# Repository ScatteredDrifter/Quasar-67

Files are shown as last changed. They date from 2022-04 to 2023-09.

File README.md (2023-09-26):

# Quasar-67
A Lumberjack Ortho keyboard for the kbd67-lite l

made by **Bonk** and **ScatteredDrifter**

---

Measurements of the pcb are taken from [Elmos Drop in Replacement[(https://github.com/kb-elmo/67mk_E)

---

### Current Status
- rev1 pcb were ordered and **work** well so far. 
- first designs of possible middle-blocker were made and mounted.
- rev1 pcb successfully built with kbd67-lite
 
---
### Quasar-67: 

A quasar defines the center of a galaxy that emits a bright  light, creating the mirage that it is a large star. However they are actually black holes which _emit_ light, due to th massive amount of matter that sourrounds their event horizon, which they consume constantly. 
Being heavily inspired by the lumberjack [find it here](https://github.com/peej/lumberjack-keyboard) this keyboard aims to fit within the affordable kbd67-lite while getting rid of the present 60% keyboard it is.

To build one yourself, you'll need the pcb - files can be find in production/... - and a plate made of the material you prefer. All production files can be found within this repository. 

### Build Guide: 

**// ought to be added before release 02 //**

### Features: 
- RP2040 
- Usb-C connector 
- short circuit protection to secure the board from electrical discharges and similiar. 
- cutouts for the kbd67-lite 
- two Iso-Enters for thumb cluster >> included in most base-kits 
- options to build this board with 2 encoders on each side 
- option between 5x6 or 5x5 cluster for each side 
- option to mount a Cirque trackpad
- layout options
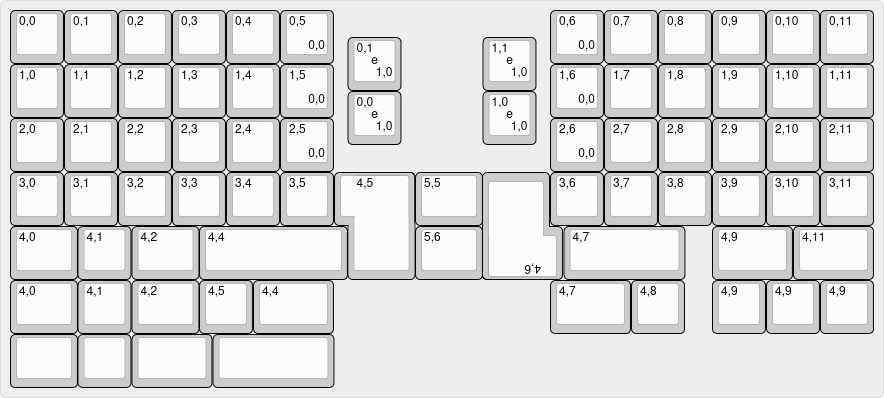
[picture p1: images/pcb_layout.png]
layout of Quasar-67


---
### Images:

**// to be added //**

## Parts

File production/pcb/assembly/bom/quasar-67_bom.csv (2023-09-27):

Comment | Designator | Footprint | LCSC
10u | C1,C4,C17 | Capacitor_SMD:C_0805_2012Metric | C91245
22pf | C2,C3 | Capacitor_SMD:C_0805_2012Metric | C1804
100n | C5,C6,C7,C9,C11,C12,C13,C14 | Capacitor_SMD:C_0805_2012Metric | C49678
1u | C8,C10 | Capacitor_SMD:C_0805_2012Metric | C28323
BAV70 | D1,D2,D3,D55,D56,D203,D407,D506,D809,D1011,D1213,D1415,D1617,D1819,D2021,D2223,D2425,D2627,D2829,D3031,D3233,D3435,D3637,D3839,D4041,D4243,D4445,D4647,D10011,D110111,D210211,D310311,D410411 | Package_TO_SOT_SMD:SOT-23 | C68978
WS2812B | DLED0,DLED1,DLED2,DLED3,DLED4,DLED0.5 | LED_SMD:LED_WS2812B_PLCC4_5.0x5.0mm_P3.2mm
RotaryEncoder_Switch | ENCODERLEFT1,ENCODERRIGHT1,ENCODERLEFT2,ENCODERRIGHT2 | Rotary_Encoder:RotaryEncoder_Alps_EC11E-Switch_Vertical_H20mm
polyfuse | F0 | Fuse:Fuse_1206_3216Metric | C69688
USB_C_Receptacle_USB2.0 | J0 | Connector_USB:USB_C_Receptacle_HRO_TYPE-C-31-M-12 | C165948
BREAKOUT | J1 | Connector_PinSocket_2.54mm:PinSocket_1x05_P2.54mm_Vertical
Conn_01x04_Female | J2 | Connector_PinHeader_2.54mm:PinHeader_1x04_P2.54mm_Vertical
Conn_01x04_Male | J3 | kbd:Aio3_jst | C160404
Conn_01x01_Male | J4 | Connector_PinSocket_1.27mm:PinSocket_1x01_P1.27mm_Vertical
Conn_01x02_Female | J5 | Connector_PinHeader_2.54mm:PinHeader_1x02_P2.54mm_Vertical
Conn_01x04_Male | J6 | Connector_PinSocket_2.54mm:PinSocket_1x04_P2.54mm_Vertical
1k | R1,R5 | Resistor_SMD:R_0805_2012Metric | C115316
27 | R3,R4 | Resistor_SMD:R_0805_2012Metric | C104170
5.1k | R6,R7 | Resistor_SMD:R_0805_2012Metric | C27834
10k | R8 | Resistor_SMD:R_0805_2012Metric | C115309
RESET | SW-1 | Keebio-Parts:SW_SPST_TL3342 | C2886894
RESET | SW-2 | Keebio-Parts:SW_SPST_TL3342 | C2886894
SW_SPST | SW0,SW1,SW2,SW3,SW4,SW5,SW6,SW7,SW8,SW9,SW1.0,SW10,SW1.1,SW11,SW1.2,SW12,SW13,SW14,SW15,SW16,SW17,SW18,SW19,SW20,SW21,SW22,SW23,SW24,SW25,SW26,SW27,SW28,SW29,SW30,SW31,SW32,SW33,SW34,SW35,SW36,SW37,SW38,SW39,SW40,SW41,SW42,SW43,SW44,SW45,SW46,SW47,SW48,SW49,SW50,SW51,SW52,SW53,SW55,SW56,SW57,SW110,SW111,SW210,SW211,SW310,SW311,SW411 | Keebio-Parts:MX-Alps-Choc-1U-NoLED
XC6206PxxxMR | U1 | Package_TO_SOT_SMD:SOT-23 | C347376
W25Q128JVS | U2 | Package_SO:SOIC-8_5.23x5.23mm_P1.27mm | C97521
RP2040 | U3 | RP2040:RP2040-QFN-56 | C2040
SRV05-4 | U44 | Package_TO_SOT_SMD:SOT-23-6 | C85364
12MHZ Crystal | Y0 | Crystal:Crystal_SMD_3225-4Pin_3.2x2.5mm | C9002

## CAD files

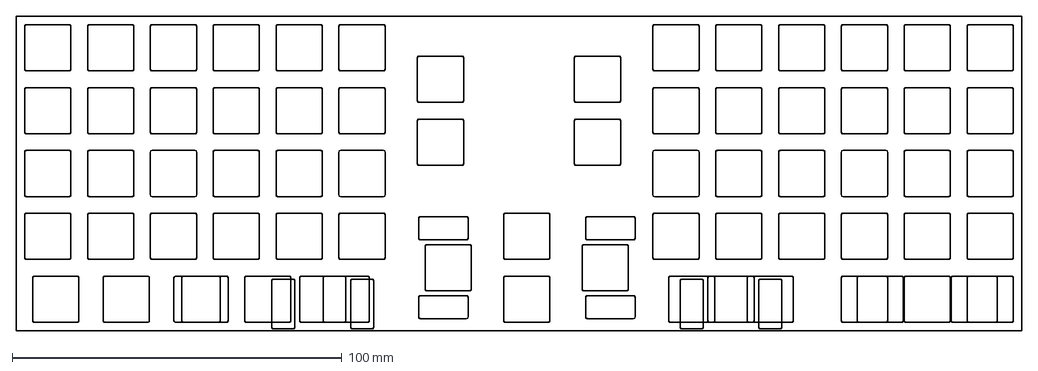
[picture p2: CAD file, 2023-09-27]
newest_plate_pcb_alignment.dxf
304.8 x 95.2 mm

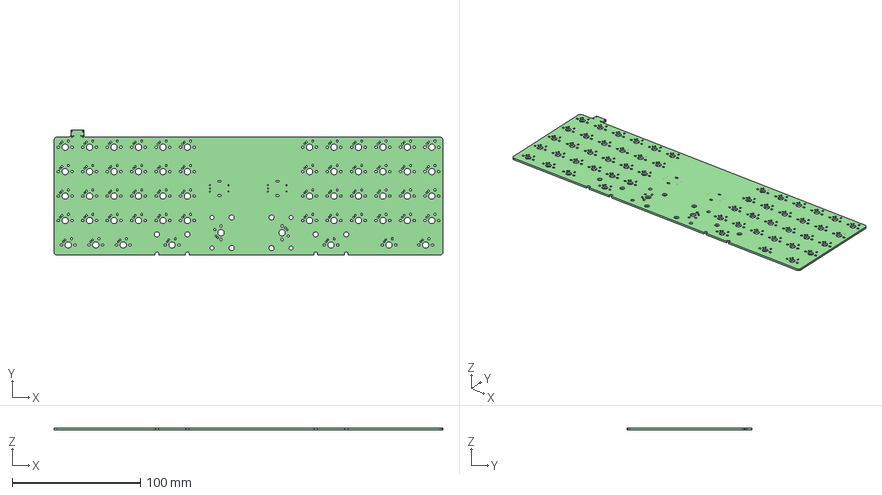
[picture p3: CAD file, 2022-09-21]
pcb/32u4.step
303.2 x 97.6 x 1.60 mm

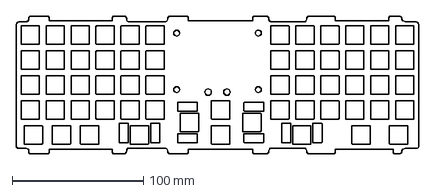
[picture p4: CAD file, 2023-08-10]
plate/Switchplate-maxkeys.dxf
307.2 x 104.9 mm

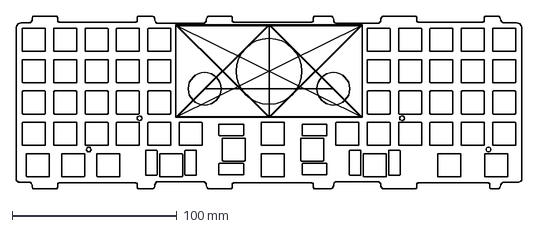
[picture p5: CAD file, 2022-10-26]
newplate_quasar.dxf
307.3 x 104.9 mm

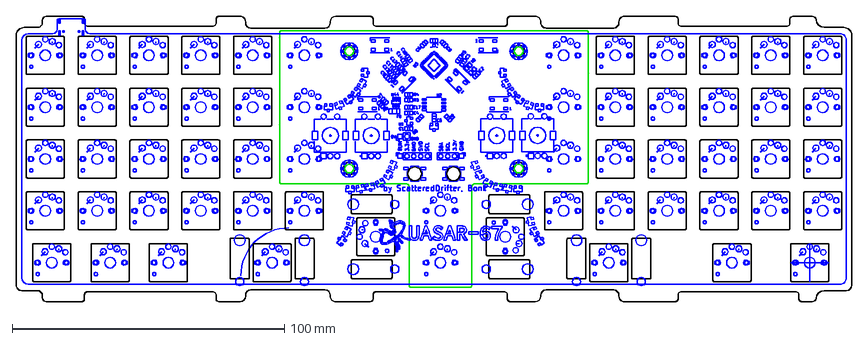
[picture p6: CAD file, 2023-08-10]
plate/All-Plates-4x5-isothumbs-quasarrgb.dxf
307.3 x 104.9 mm

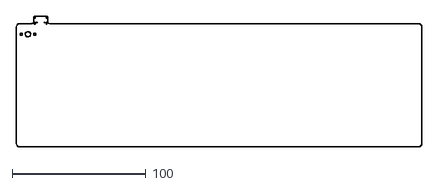
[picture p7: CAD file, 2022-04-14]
elmo_outlines_kbd67.dxf
303.2 x 97.6

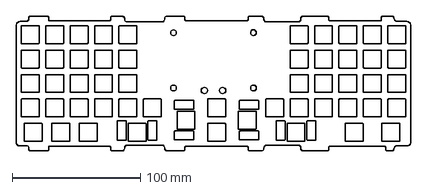
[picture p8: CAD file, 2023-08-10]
plate/Switchplate-botkeys.dxf
307.2 x 104.9 mm

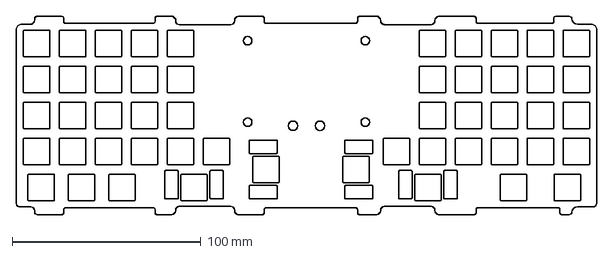
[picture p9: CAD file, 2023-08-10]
plate/Switchplate-4x5-isothumbs.dxf
307.2 x 104.9 mm

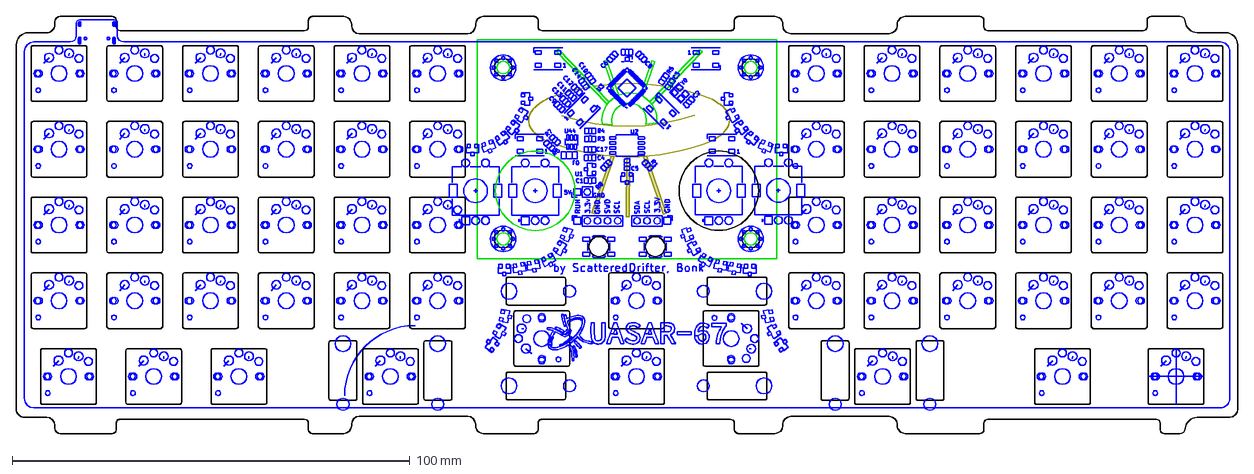
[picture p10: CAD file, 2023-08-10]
plate/All-Plates-maxkeys-encoder.dxf
307.3 x 104.9 mm

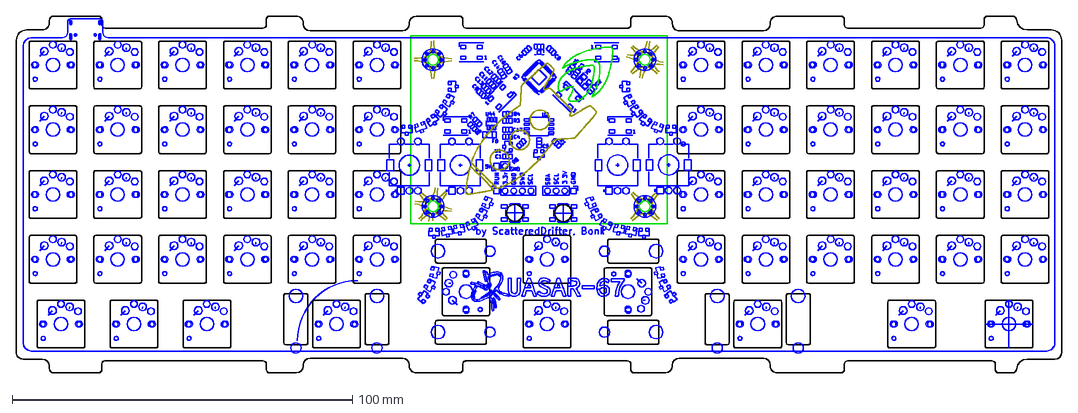
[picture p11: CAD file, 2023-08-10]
plate/All-Plates-maxkeys-rocket.dxf
307.3 x 104.9 mm

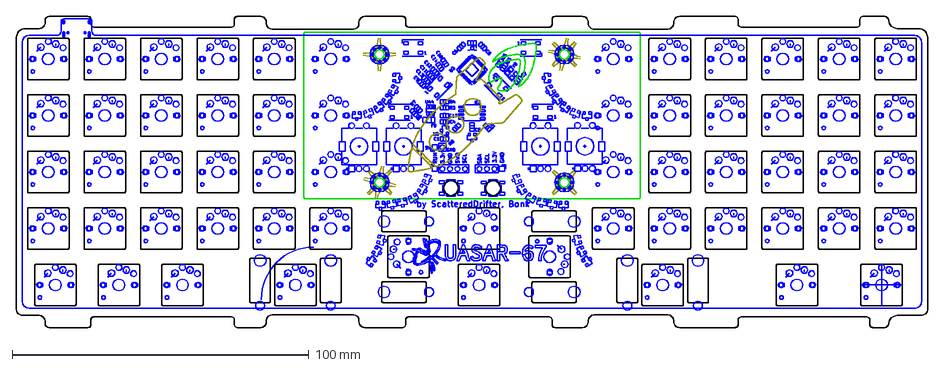
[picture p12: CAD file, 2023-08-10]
plate/All-Plates-botkeys-rocket.dxf
307.3 x 104.9 mm

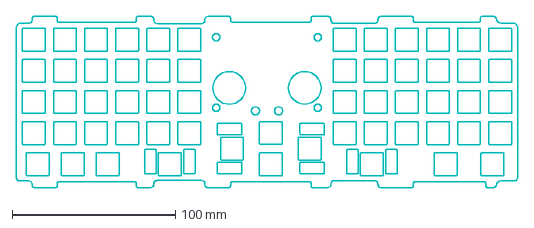
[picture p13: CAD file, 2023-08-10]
plate/Switchplate-maxkeys-encoder.dxf
307.2 x 104.9 mm

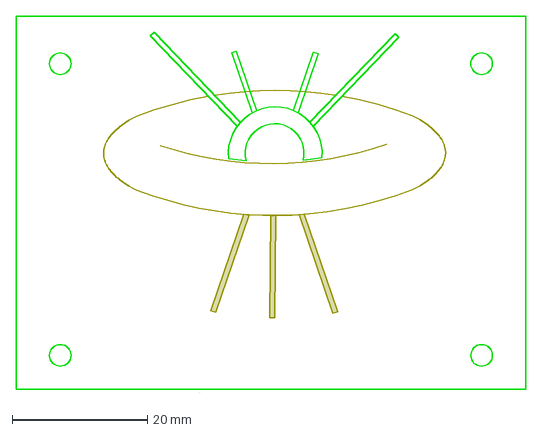
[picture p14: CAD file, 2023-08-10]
plate/Top-Plate-quasar-maxkeys.dxf
75.2 x 55.7 mm

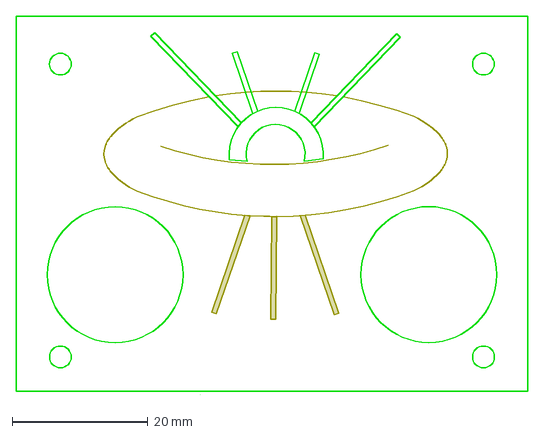
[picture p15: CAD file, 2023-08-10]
plate/Top-Plate-quasar-encoder-maxkeys.dxf
75.2 x 55.7 mm

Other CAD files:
plate/Top-Plate-rocket-botkeys.dxf
plate/Top-Plate-rocket-4x5-isothumbs.dxf
plate/Top-Plate-quasar-4x5-isothumbs.dxf
plate/Top-Plate-rgb-quasar.dxf
plate/Top-Plate-rocket.dxf
plate/~All-Plates-4x5-isothumbs-quasarrgb.dxf

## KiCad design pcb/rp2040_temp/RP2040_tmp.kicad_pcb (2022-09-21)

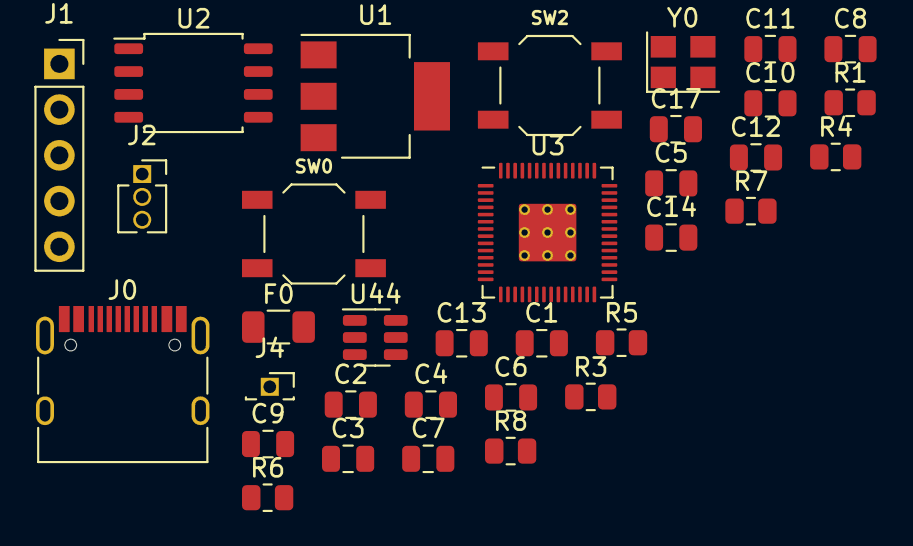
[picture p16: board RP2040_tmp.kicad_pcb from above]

Board: 2 copper layers, 34 parts (0 on the bottom side), 25 nets, no tracks yet.

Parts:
C1, C4, C17: 10u; C_0805_2012Metric
C2, C3: 22pf; C_0805_2012Metric
C5, C6, C7, C9, C11, C12, C13, C14: 100n; C_0805_2012Metric
C8, C10: 1u; C_0805_2012Metric
F0: polyfuse; Fuse_1206_3216Metric
J0: USB_C_Receptacle_USB2.0; USB_C_Receptacle_HRO_TYPE-C-31-M-12
J1: BREAKOUT; PinSocket_1x05_P2.54mm_Vertical
J2: Conn_01x03_Male; PinSocket_1x03_P1.27mm_Vertical
J4: Conn_01x01_Male; PinSocket_1x01_P1.27mm_Vertical
R1, R5: 1k; R_0805_2012Metric
R3, R4: 27; R_0805_2012Metric
R6, R7: 5.1k; R_0805_2012Metric
R8: 10k; R_0805_2012Metric
SW0, SW2: RESET; SW_SPST_TL3342
U1: NCP1117-3.3_SOT223; SOT-223-3_TabPin2
U2: W25Q128JVS; SOIC-8_5.23x5.23mm_P1.27mm
U3: RP2040; RP2040-QFN-56
U44: SRV05-4; SOT-23-6
Y0: 12MHZ Crystal; Crystal_SMD_3225-4Pin_3.2x2.5mm

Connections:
+1V1: C6.1, C7.1, C8.1, J4.1, U3.23 (DVDD), U3.45 (VREG_VOUT), U3.50 (DVDD)
+3V3: C4.1, C5.1, C9.1, C10.1, C11.1, C12.1, C13.1, C14.1, C17.1, J1.2, R8.2, U1.2 (VO), U2.8 (VCC), U3.1 (IOVDD), U3.10 (IOVDD), U3.22 (IOVDD), U3.33 (IOVDD), U3.42 (IOVDD), U3.43 (ADC_AVDD), U3.44 (VREG_IN), U3.48 (USB_VDD), U3.49 (IOVDD)
+5V: C1.1, F0.2, J2.1, U1.3 (VI), U44.5 (VP)
/QSPI_SCLK: U2.6 (CLK), U3.52 (QSPI_SCLK)
/QSPI_SD0: U2.5 (DI(IO0)), U3.53 (QSPI_SD0)
/QSPI_SD1: U2.2 (DO(IO1)), U3.55 (QSPI_SD1)
/QSPI_SD2: U2.3 (IO2), U3.54 (QSPI_SD2)
/QSPI_SD3: U2.7 (IO3), U3.51 (QSPI_SD3)
/QSPI_SS: R1.1, U2.1 (~CS), U3.56 (QSPI_SS)
/RUN: J1.1, R8.1, SW2.2, U3.26 (RUN)
/SWCLK: J1.5, U3.24 (SWCLK)
/SWD: J1.4, U3.25 (SWD)
/USB_D+: J0.A6 (D+), J0.B6 (D+), R3.1, U44.3 (IO2)
/USB_D-: J0.A7 (D-), J0.B7 (D-), R4.1, U44.6 (IO4)
/XIN: C2.1, U3.20 (XIN), Y0.3
/XOUT: R5.1, U3.21 (XOUT)
/~USB_BOOT: R1.2, SW0.2
GND: C1.2, C2.2, C3.2, C4.2, C5.2, C6.2, C7.2, C8.2, C9.2, C10.2, C11.2, C12.2, C13.2, C14.2, C17.2, J0.A1 (GND), J0.A12 (GND), J0.B1 (GND), J0.B12 (GND), J0.S1 (SHIELD), J1.3, J2.2, R6.2, R7.2, SW0.1, SW2.1, U1.1 (GND), U2.4 (GND), U3.19 (TESTEN), U3.57 (GND), U44.2 (VN), Y0.2, Y0.4
LED_GLOW: J2.3, U3.8 (GPIO6)
unnamed: C3.1, R5.2, Y0.1
unnamed: J0.A5 (CC1), R7.1
unnamed: J0.B5 (CC2), R6.1
unnamed: R3.2, U3.47 (USB_DP)
unnamed: R4.2, U3.46 (USB_DM)
VBUS: F0.1, J0.A4 (VBUS), J0.A9 (VBUS), J0.B4 (VBUS), J0.B9 (VBUS)

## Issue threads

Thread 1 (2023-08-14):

Add JST-Connector

ScatteredDrifter, 2023-08-14:
To support a wider range of 65% Boards we could likely add a breakout for **JST-Connectors**.
Because some boards require special placements / positions we ought to find a **universal** or find a compromise.

I will leave this open and hope for contribution from @manudergrohse

manudergrohse, 2023-08-14:
hi, der echte M4NU hier.
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

ScatteredDrifter, 2023-08-24:
Thank you for the description.
The proposed Connector will link the internal pcb with an unified daughterboard, right?
Hence I will make it an alternative you can solder and use if you like ?

manudergrohse, 2023-08-31:
yes to both 👍

Closed 2023-09-18.

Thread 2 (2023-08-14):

optional 65 Blocker

ScatteredDrifter, 2023-08-14:
for a wider support of **cases** we could make the **65 Blocker** optional.
This means adding **mousebites** so that one could cut those of if they insist to.

We could also leave it out entirely, making support easier by decreasing the amount of work ( especially regarding the hazardous dust of pcbs)

I would like your comment on it @Sturek

Sturek, 2023-08-14:
I would just make a cutout in the PCB for the blocker. I don't think there is a relevant downside to having the cutout.

ScatteredDrifter, 2023-08-24:
Yea thats likely the easiest solution especially because its not exposing users with possible dust and other hazardous operations.

I will consider and imclude it in the next revision of this pcb, thankyou!

Closed 2023-09-18.

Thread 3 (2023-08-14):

Issues for __second revision__

ScatteredDrifter, 2023-08-14:
the first release came with some issues.
Those has been noted and ought to be solved for the next iteration.
Namely this means :
- [ ] reset switches colliding with Plate
- [ ] adding screws for **blocker**
- [ ] misc, design choices?

Sturek, 2023-08-14:
I modified the plate to have holes above the reset switches, so that should be fixed.

The plate and blocker have also been modified for m3 screws and standoffs.

I would add one thing: it would be great, if the two top LEDs were lower, so you could put something on the PCB to block the light bleed. Right now you need to put it between case and PCB/plate.

Closed 2023-09-18.

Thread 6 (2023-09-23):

add holes to solder usb-daughterboard

ScatteredDrifter, 2023-09-23:
In case one does not make use of the provided JST-port  - or its obstructed by some other part - I should provide an **alternative** to solder on the required cables.

**ought to be done** before the second revision #5 is done

ScatteredDrifter, 2023-09-26:
I will include 2.54mm holes to manually solder a jst-connector-cable in case the attached part is obstructing mounting within a case or similar.
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

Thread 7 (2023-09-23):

add cutouts for bakeneko-style cases

ScatteredDrifter, 2023-09-23:
Those keyboard cases - which we could support with this pcb - come with certain cutouts on each side to avoid collision with the case.
I should amend those to include support for mentioned cases.

**ought to be done** before release of the second revision #5

ScatteredDrifter, 2023-09-26:
Likely difficult, because this board is generally smaller in every dimension.
I've aligned both outlines (white one is taken from the bakeneko 65, smaller green one is from Quasar ) to visualize the problem:
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

ScatteredDrifter, 2023-10-08:
We are currently waiting unitl @Sturek received their **Neo65**. This way we can check whether additional cutouts are necessary or if we could simply use this pcb in different cases ( it is smaller than most pcbs after all )

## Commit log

2022-04-14 updated pcb, finalized routing
    [32u4.kicad_sch, kbdlitepcb_outlines.dxf]
2022-07-01 Plate added
    [32u4.step, plate-2022-04-21T19 40 31.685Z.dxf, ~plate-2022-04-21T19 40 31.685Z.dxf]
2022-07-29 Updated plate
    [Plate.dxf]
2022-08-20 Finished Plate
    [Plate.dxf]
2022-08-25 Added top plate
    [~Plate.dxf]
2022-09-21 updated pcb to rp2040
    [32u4.kicad_sch, RP2040_tmp.kicad_pcb, RP2040_tmp.kicad_sch]
2022-10-26 finalized placement and pcb
    encoder and component placement was updated.
    Further deleted backups from repo
    [32u4-B_Cu.gbr, 32u4-B_Mask.gbr, 32u4-B_Paste.gbr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]
2022-10-26 cleaned repo, added gerber
    prepared for release. Added bom, pos and gerber for jlcpcb
    [quasar-67_bom.csv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]
2022-11-02 updated lcsc partnumber for ldo
    [RP2040_tmp.kicad_sch]
2022-12-23 Updated plate
    First version, we still need plates for different layout options.
    [Plate.bak000.dxf, Plate.dxf]
2022-12-23 KiCAD wants this
    Changes which layer is active.
2023-03-31 Plates and Top Plates for some configurations finished
    [All-Plates-4x5-isothumbs-quasarrgb.dxf, All-Plates-botkeys-rocket.dxf, All-Plates-maxkeys-rocket.dxf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]
2023-03-31 updated pcb
    [32u4.kicad_sch, RP2040_tmp.kicad_sch]
2023-06-26 Updated top plate coming up
    [All-Plates-maxkeys-rocket.dxf]
2023-06-26 Here is the updated top plate
    [All-Plates-maxkeys-rocket.dxf]
2023-08-10 Finished All plates 4x5
    [~All-Plates-4x5-isothumbs-quasarrgb.dxf]
2023-08-10 Finalizing plates
    [All-Plates-4x5-isothumbs-quasarrgb.bak000.dxf, All-Plates-botkeys-rocket.dxf, All-Plates-maxkeys-encoder.dxf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]
2023-08-10 Added cutouts for reset switches
    [All-Plates-4x5-isothumbs-quasarrgb.bak000.dxf, All-Plates-4x5-isothumbs-quasarrgb.dxf, All-Plates-botkeys-rocket.dxf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]
2023-08-24 modification of pcb.
    no major changes but small adjustments of layout and routing
2023-08-24 added mousebites and jst breakout
    [32u4.kicad_sch, RP2040_tmp.kicad_sch]
2023-09-17 added blocker cutout and daughterbaord breakout
    [RP2040_tmp.kicad_sch]
2023-09-17 lowered position of top leds
2023-09-26 added breakout-holes for usb, updated bom and gerber
    [32u4-B_Cu.gbr, 32u4-B_Mask.gbr, 32u4-B_Paste.gbr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]
2023-09-26 updated routing further
    [32u4.csv, RP2040_tmp.kicad_sch, Top-Plate-rgb-quasar.dxf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]
2023-09-27 updated layout options and pcb
    - updated gerber and assembly files
    - updated layout options image
    [32u4-B_Cu.gbr, 32u4-B_Mask.gbr, 32u4-B_Paste.gbr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]
2023-10-08 added silkscreen and adjusted font
2023-10-08 removed switch annotation, updated text positions
